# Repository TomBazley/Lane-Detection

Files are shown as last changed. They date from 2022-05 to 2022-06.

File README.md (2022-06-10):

# Lane Detection

A final year BEng electronics project that aims to detect lanes on a road from a live video feed. Using an FPGA, the lanes are detected by applying the sobel operator combined with searching for pixels brighter than a variable threshold.

## Demonstration

https://user-images.githubusercontent.com/62083547/172941356-2ffd6f28-229f-4e7b-8cfc-a31fc2a52e07.mp4

This demonstration shows a recording of the screen which displays the processed video. The red markers are produced by the FPGA to indicate the position of the lane.

## Schematic

[Schematic](https://github.com/TomBazley/Lane-Detection/blob/master/PCB/PCB.kicad_sch)

A circuit board was designed which includes an iCE40 FPGA, a VGA port for video input, a VGA-to-digital conversion chip, a STM32 microcontroller to configure the FPGA and VGA converter, and a display to view the processed images. The circuit board also features a power supply, overvoltage protection, and reverse polarity protection.

# PCB

[PCB1](https://github.com/TomBazley/Lane-Detection/blob/master/PCB/)
[PCB2](https://github.com/TomBazley/Lane-Detection/blob/master/PCB/)

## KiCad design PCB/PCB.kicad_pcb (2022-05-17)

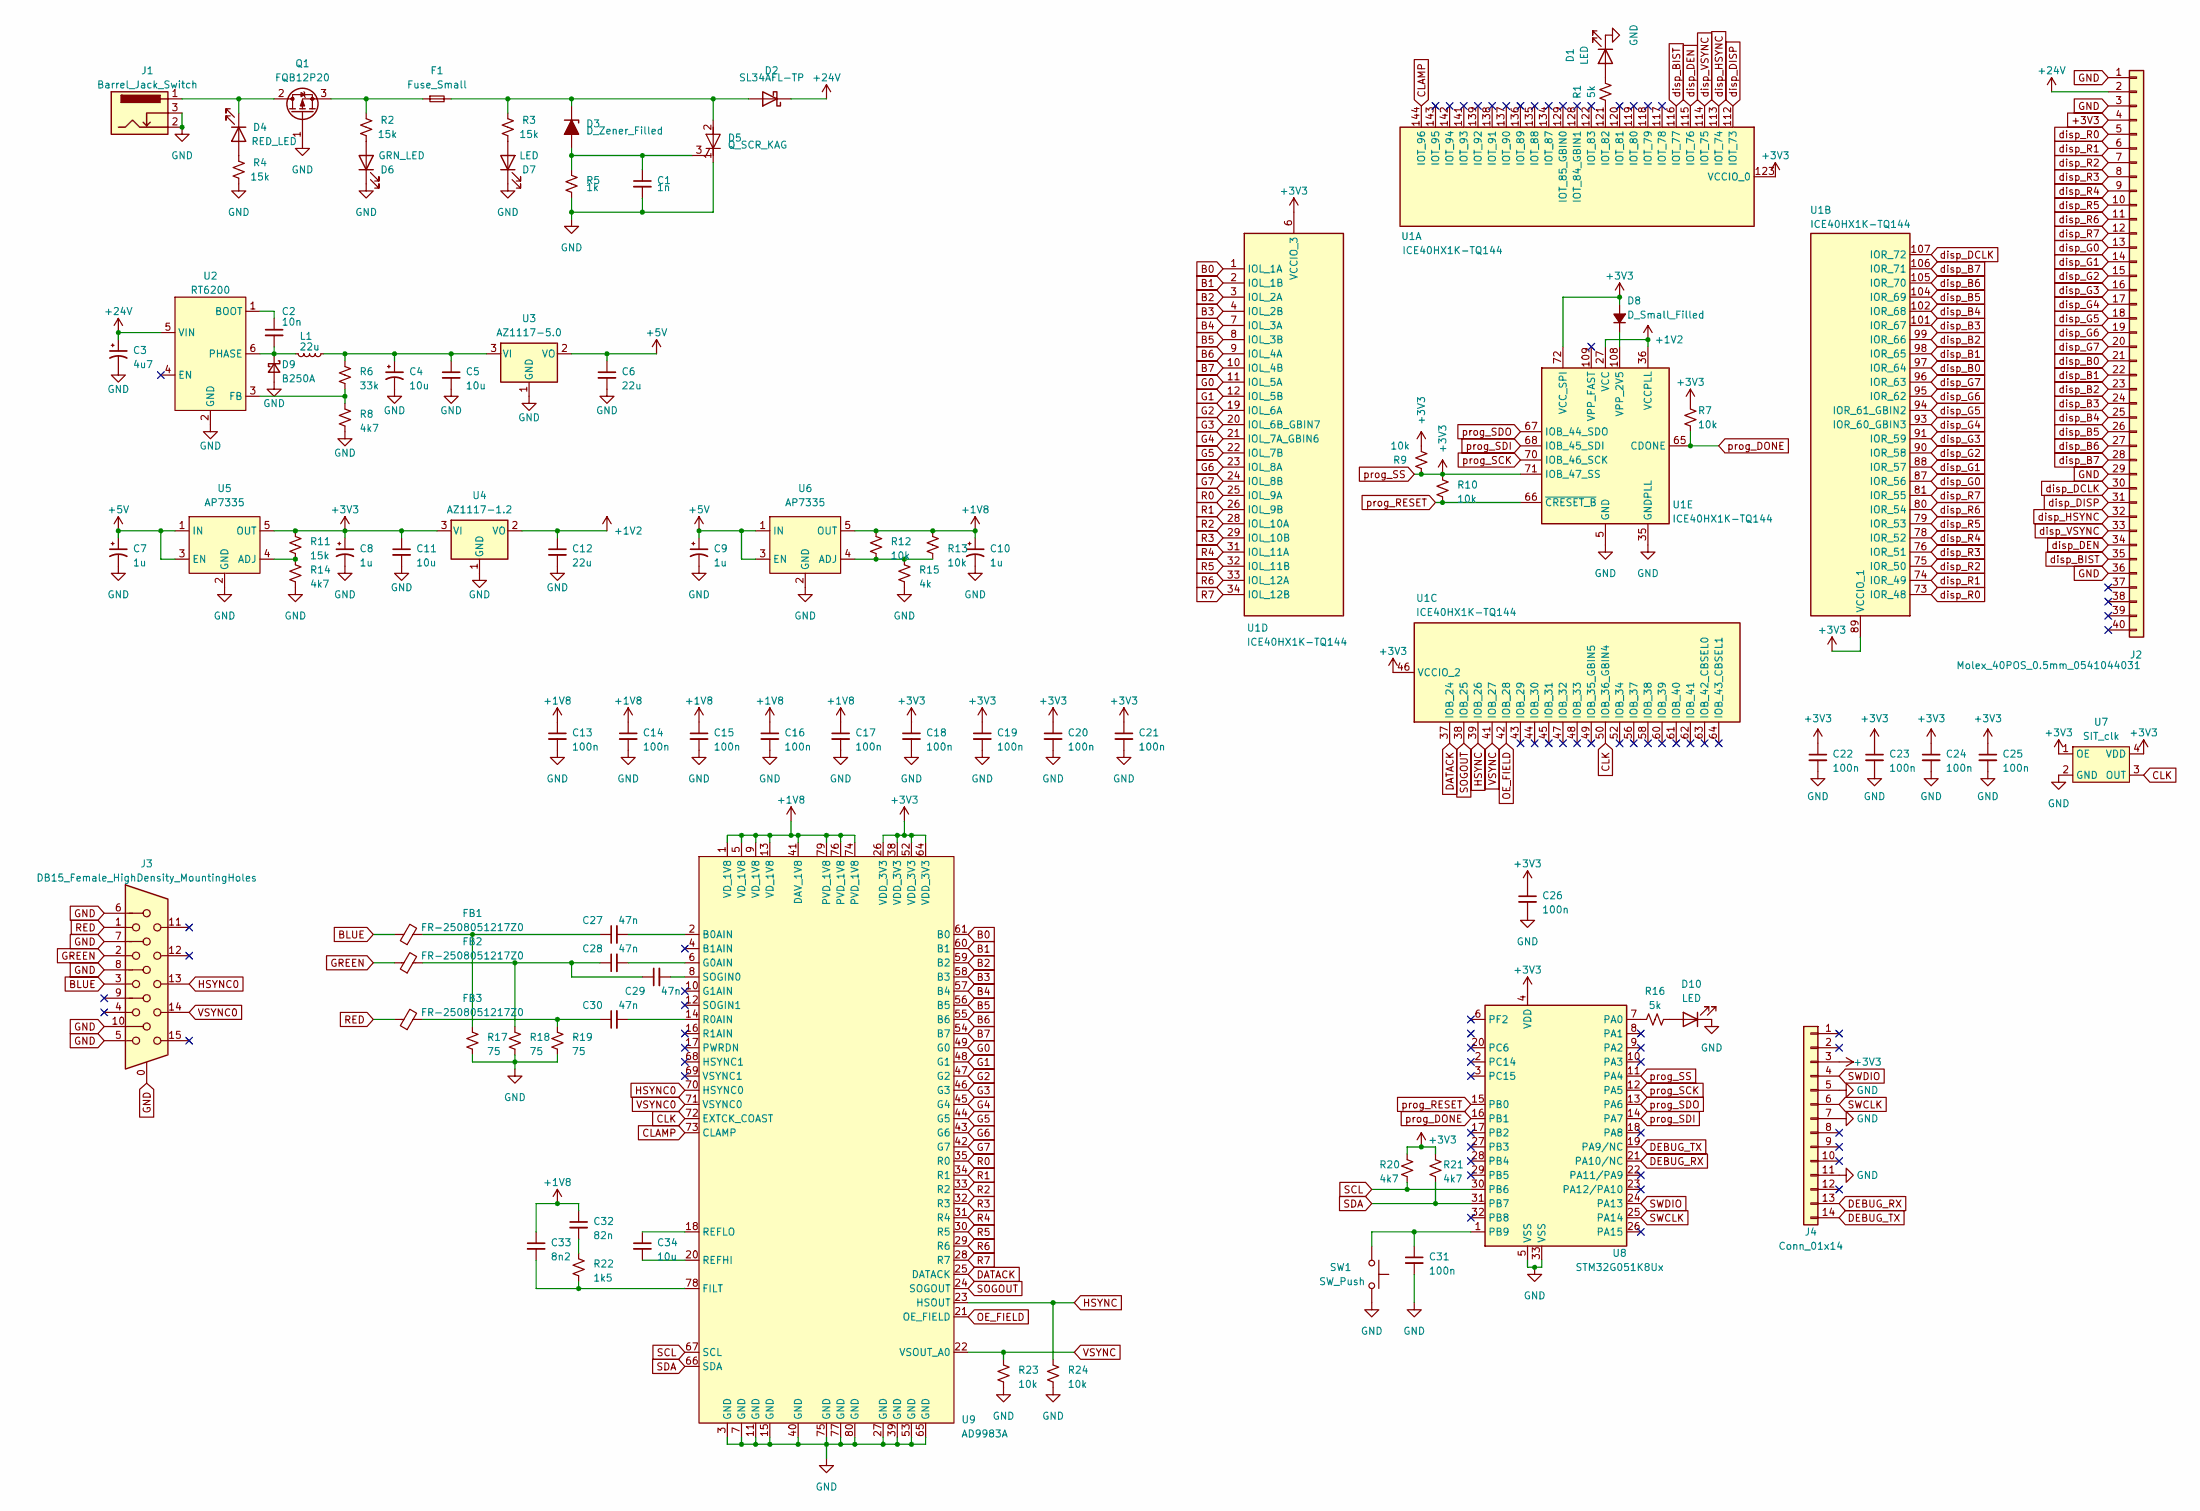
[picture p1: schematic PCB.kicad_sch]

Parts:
C1: 1n; C_0805_2012Metric
C2: 10n; C_0805_2012Metric
C3: 4u7; CP_EIA-7343-31_Kemet-D
C4: 10u; CP_EIA-7343-31_Kemet-D
C5, C11, C34: 10u; C_0805_2012Metric
C6, C12: 22u; C_0805_2012Metric
C7, C8, C9, C10: 1u; CP_EIA-3528-21_Kemet-B
C13, C14, C15, C16, C17, C18, C19, C20, C21, C22, C23, C24, C25, C26, C31: 100n; C_0805_2012Metric
C27, C28, C29, C30: 47n; C_0805_2012Metric
C32: 82n; C_0805_2012Metric
C33: 8n2; C_0805_2012Metric
D1, D7, D10: LED; LED_0603_1608Metric
D2: SL34AFL-TP; D_SMA
D3: D_Zener_Filled; D_SOD-123
D4: RED_LED; LED_0603_1608Metric
D5: Q_SCR_KAG; TO-252-2
D6: GRN_LED; LED_0603_1608Metric
D8: D_Small_Filled; D_SOD-123
D9: B250A; D_SMA
F1: Fuse_Small; Fuse_1210_3225Metric
FB1, FB2, FB3: FR-2508051217Z0; L_0805_2012Metric
J1: Barrel_Jack_Switch; Barrel PJ-002BH-SMT-TR
J2: Molex_40POS_0.5mm_0541044031
J3: DB15_Female_HighDensity_MountingHoles; VGA 10090926-P154XLF
J4: Conn_01x14; SAMTECH-FTSH-107-01-F-DV-K
L1: 22u; IHLP2525CZER220M11
Q1: FQB12P20; TO-263-2
R1, R16: 5k; R_0805_2012Metric
R2, R3, R4, R11: 15k; R_0805_2012Metric
R5: 1k; R_0805_2012Metric
R6: 33k; R_0805_2012Metric
R7, R9, R10, R12, R13, R23, R24: 10k; R_0805_2012Metric
R8, R14, R20, R21: 4k7; R_0805_2012Metric
R15: 4k; R_0805_2012Metric
R17, R18, R19: 75; R_0805_2012Metric
R22: 1k5; R_0805_2012Metric
SW1: SW_Push; SW_SPST_PTS645
U1: ICE40HX1K-TQ144; TQFP-144_20x20mm_P0.5mm
U2: RT6200; SOT-23-6
U3: AZ1117-5.0; SOT-223
U4: AZ1117-1.2; SOT-223
U5, U6: AP7335; SOT-23-5
U7: SIT_clk; SIT8008xx-1x
U8: STM32G051K8Ux; QFN-32-1EP_5x5mm_P0.5mm_EP3.45x3.45mm
U9: AD9983A; LQFP-80_14x14mm_P0.65mm

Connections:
+1V2: C12.1, U1.27 (VCC), U1.36 (VCCPLL), U1.51 (VCC), U1.92 (VCC), U1.111 (VCC), U4.2 (VO)
+1V8: C10.1, C13.1, C14.1, C15.1, C16.1, C17.1, C32.1, C33.1, R12.1, R13.1, U6.5 (OUT), U9.1 (VD_1V8), U9.5 (VD_1V8), U9.9 (VD_1V8), U9.13 (VD_1V8), U9.41 (DAV_1V8), U9.74 (PVD_1V8), U9.76 (PVD_1V8), U9.79 (PVD_1V8)
+3V3: C8.1, C11.1, C18.1, C19.1, C20.1, C21.1, C22.1, C23.1, C24.1, C25.1, C26.1, D8.2 (A), J2.4, J4.3, R7.1, R9.1, R9.2, R10.1, R11.1, R20.1, R21.1, U1.6 (VCCIO_3), U1.30 (VCCIO_3), U1.46 (VCCIO_2), U1.57 (VCCIO_2), U1.71 (IOB_47_SS), U1.72 (VCC_SPI), U1.89 (VCCIO_1), U1.100 (VCCIO_1), U1.123 (VCCIO_0), U1.133 (VCCIO_0), U4.3 (VI), U5.5 (OUT), U7.1 (OE), U7.4 (VDD), U8.4 (VDD), U8.11 (PA4), U9.26 (VDD_3V3), U9.38 (VDD_3V3), U9.52 (VDD_3V3), U9.64 (VDD_3V3)
+5V: C6.1, C7.1, C9.1, U3.2 (VO), U5.1 (IN), U5.3 (EN), U6.1 (IN), U6.3 (EN)
+24V: C3.1, D2.1 (K), J2.2, U2.5 (VIN)
B0: U1.1 (IOL_1A), U9.61 (B0)
B1: U1.2 (IOL_1B), U9.60 (B1)
B2: U1.3 (IOL_2A), U9.59 (B2)
B3: U1.4 (IOL_2B), U9.58 (B3)
B4: U1.7 (IOL_3A), U9.57 (B4)
B5: U1.8 (IOL_3B), U9.56 (B5)
B6: U1.9 (IOL_4A), U9.55 (B6)
B7: U1.10 (IOL_4B), U9.54 (B7)
BLUE: FB1.1, J3.3
CLAMP: U1.144 (IOT_96), U9.73 (CLAMP)
CLK: U1.50 (IOB_36_GBIN4), U7.3 (OUT), U9.72 (EXTCK_COAST)
DATACK: U1.37 (IOB_24), U9.25 (DATACK)
DEBUG_RX: J4.13, U8.21 (PA10/NC)
DEBUG_TX: J4.14, U8.19 (PA9/NC)
G0: U1.11 (IOL_5A), U9.49 (G0)
G1: U1.12 (IOL_5B), U9.48 (G1)
G2: U1.19 (IOL_6A), U9.47 (G2)
G3: U1.20 (IOL_6B_GBIN7), U9.46 (G3)
G4: U1.21 (IOL_7A_GBIN6), U9.45 (G4)
G5: U1.22 (IOL_7B), U9.44 (G5)
G6: U1.23 (IOL_8A), U9.43 (G6)
G7: U1.24 (IOL_8B), U9.42 (G7)
GND: C1.2, C3.2, C4.2, C5.2, C6.2, C7.2, C8.2, C9.2, C10.2, C11.2, C12.2, C13.2, C14.2, C15.2, C16.2, C17.2, C18.2, C19.2, C20.2, C21.2, C22.2, C23.2, C24.2, C25.2, C26.2, C31.2, D1.1 (K), D5.1 (K), D6.1 (K), D7.1 (K), D9.2 (A), D10.1 (K), J1.2, J1.3, J2.1, J2.3, J2.29, J2.36, J3.0, J3.5, J3.6, J3.7, J3.8, J3.10, J4.5, J4.7, J4.11, Q1.1 (G), R4.2, R5.2, R8.2, R14.2, R15.2, R17.2, R18.2, R19.2, R23.2, R24.2, SW1.2, U1.5 (GND), U1.13 (GND), U1.14 (GND), U1.35 (GNDPLL), U1.59 (GND), U1.69 (GND), U1.86 (GND), U1.103 (GND), U1.132 (GND), U1.140 (GND), U2.2 (GND), U3.1 (GND), U4.1 (GND), U5.2 (GND), U6.2 (GND), U7.2 (GND), U8.5 (VSS), U8.33 (VSS), U9.3 (GND), U9.7 (GND), U9.11 (GND), U9.15 (GND), U9.27 (GND), U9.39 (GND), U9.40 (GND), U9.53 (GND), U9.65 (GND), U9.75 (GND), U9.77 (GND), U9.80 (GND)
GREEN: FB2.1, J3.2
HSYNC: R24.1, U1.39 (IOB_26), U9.23 (HSOUT)
HSYNC0: J3.13, U9.70 (HSYNC0)
unnamed: C27.1, FB1.2, R17.1
unnamed: C28.1, C29.1, FB2.2, R18.1
unnamed: C30.1, FB3.2, R19.1
unnamed: C32.2, R22.1
unnamed: D1.2 (A), R1.2
unnamed: D2.2 (A), D3.1 (K), D5.2 (A), F1.2, R3.1
unnamed: C1.1, D3.2 (A), D5.3 (G), R5.1
unnamed: D4.2 (A), R4.1
unnamed: D4.1 (K), J1.1, Q1.2 (D)
unnamed: D6.2 (A), R2.2
unnamed: D7.2 (A), R3.2
unnamed: D8.1 (K), U1.108 (VPP_2V5)
unnamed: C2.2, D9.1 (K), L1.1, U2.6 (PHASE)
unnamed: D10.2 (A), R16.2
unnamed: F1.1, Q1.3 (S), R2.1
unnamed: R1.1, U1.121 (IOT_82)
unnamed: C2.1, U2.1 (BOOT)
unnamed: R6.2, R8.1, U2.3 (FB)
unnamed: C4.1, C5.1, L1.2, R6.1, U3.3 (VI)
unnamed: R11.2, R14.1, U5.4 (ADJ)
unnamed: R12.2, R13.2, R15.1, U6.4 (ADJ)
unnamed: R16.1, U8.7 (PA0)
unnamed: C31.1, SW1.1, U8.1 (PB9)
unnamed: C27.2, U9.2 (B0AIN)
unnamed: C33.2, R22.2, U9.78 (FILT)
unnamed: C28.2, U9.6 (G0AIN)
unnamed: C30.2, U9.14 (R0AIN)
unnamed: C34.2, U9.20 (REFHI)
unnamed: C34.1, U9.18 (REFLO)
unnamed: C29.2, U9.8 (SOGIN0)
OE_FIELD: U1.42 (IOB_28), U9.21 (OE_FIELD)
R0: U1.25 (IOL_9A), U9.35 (R0)
R1: U1.26 (IOL_9B), U9.34 (R1)
R2: U1.28 (IOL_10A), U9.33 (R2)
R3: U1.29 (IOL_10B), U9.32 (R3)
R4: U1.31 (IOL_11A), U9.31 (R4)
R5: U1.32 (IOL_11B), U9.30 (R5)
R6: U1.33 (IOL_12A), U9.29 (R6)
R7: U1.34 (IOL_12B), U9.28 (R7)
RED: FB3.1, J3.1
SCL: R20.2, U8.30 (PB6), U9.67 (SCL)
SDA: R21.2, U8.31 (PB7), U9.66 (SDA)
SOGOUT: U1.38 (IOB_25), U9.24 (SOGOUT)
SWCLK: J4.6, U8.25 (PA14)
SWDIO: J4.4, U8.24 (PA13)
VSYNC: R23.1, U1.41 (IOB_27), U9.22 (VSOUT_A0)
VSYNC0: J3.14, U9.71 (VSYNC0)
disp_B0: J2.21, U1.97 (IOR_64)
disp_B1: J2.22, U1.98 (IOR_65)
disp_B2: J2.23, U1.99 (IOR_66)
disp_B3: J2.24, U1.101 (IOR_67)
disp_B4: J2.25, U1.102 (IOR_68)
disp_B5: J2.26, U1.104 (IOR_69)
disp_B6: J2.27, U1.105 (IOR_70)
disp_B7: J2.28, U1.106 (IOR_71)
disp_BIST: J2.35, U1.116 (IOT_77)
disp_DCLK: J2.30, U1.107 (IOR_72)
disp_DEN: J2.34, U1.115 (IOT_76)
disp_DISP: J2.31, U1.112 (IOT_73)
disp_G0: J2.13, U1.87 (IOR_56)
disp_G1: J2.14, U1.88 (IOR_57)
disp_G2: J2.15, U1.90 (IOR_58)
disp_G3: J2.16, U1.91 (IOR_59)
disp_G4: J2.17, U1.93 (IOR_60_GBIN3)
disp_G5: J2.18, U1.94 (IOR_61_GBIN2)
disp_G6: J2.19, U1.95 (IOR_62)
disp_G7: J2.20, U1.96 (IOR_63)
disp_HSYNC: J2.32, U1.113 (IOT_74)
disp_R0: J2.5, U1.73 (IOR_48)
disp_R1: J2.6, U1.74 (IOR_49)
disp_R2: J2.7, U1.75 (IOR_50)
disp_R3: J2.8, U1.76 (IOR_51)
disp_R4: J2.9, U1.78 (IOR_52)
disp_R5: J2.10, U1.79 (IOR_53)
disp_R6: J2.11, U1.80 (IOR_54)
disp_R7: J2.12, U1.81 (IOR_55)
disp_VSYNC: J2.33, U1.114 (IOT_75)
prog_DONE: R7.2, U1.65 (CDONE), U8.16 (PB1)
prog_RESET: R10.2, U1.66 (~CRESET_B), U8.15 (PB0)
prog_SCK: U1.70 (IOB_46_SCK), U8.12 (PA5)
prog_SDI: U1.68 (IOB_45_SDI), U8.14 (PA7)
prog_SDO: U1.67 (IOB_44_SDO), U8.13 (PA6)

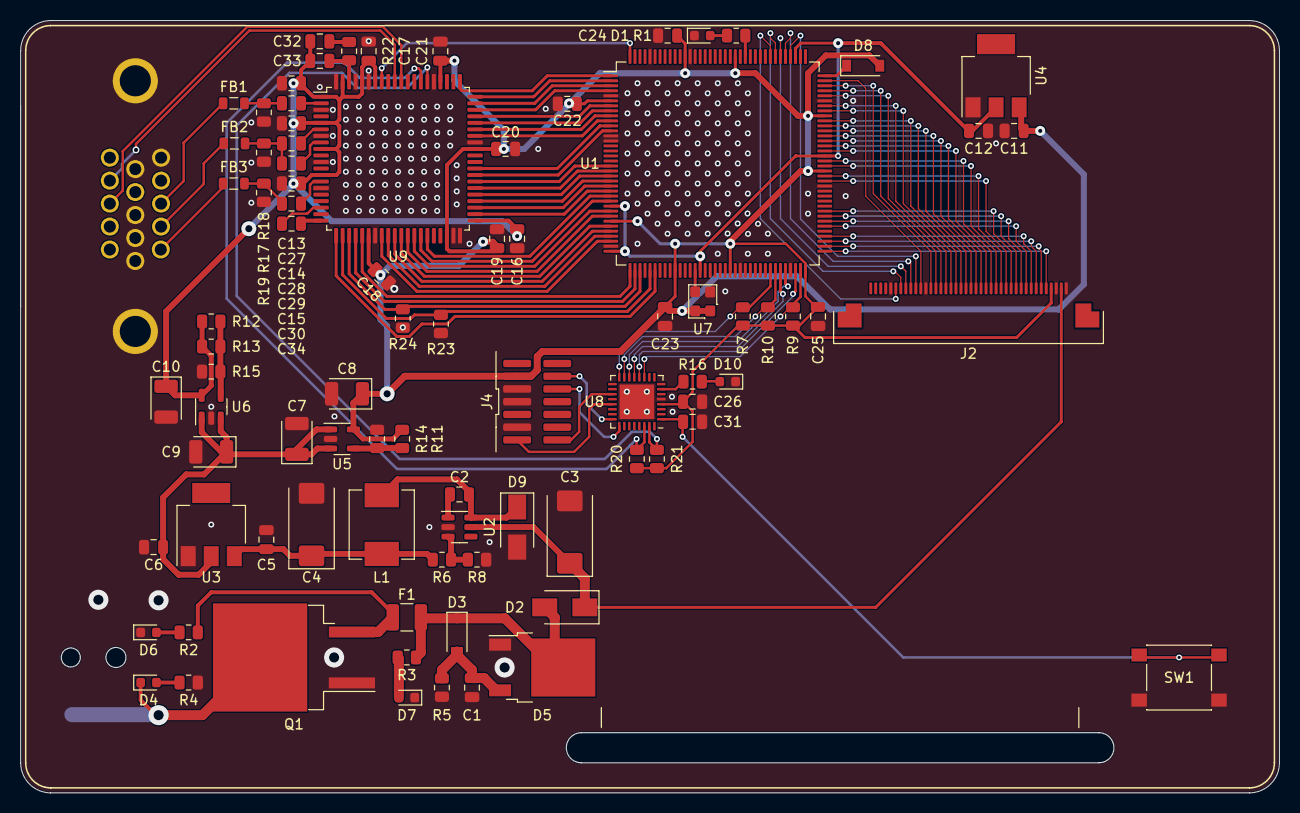
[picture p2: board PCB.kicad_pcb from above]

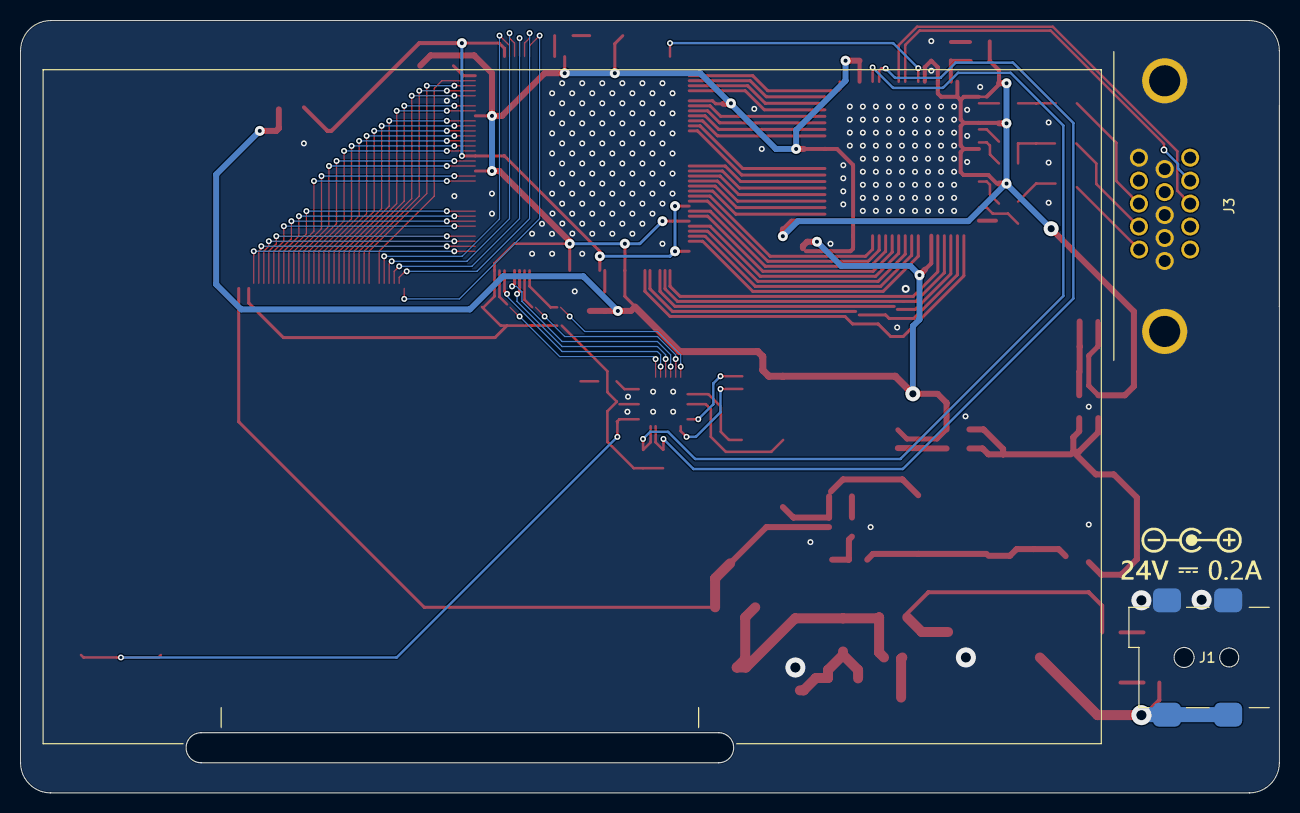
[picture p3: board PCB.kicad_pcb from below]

Board: 2 copper layers, 125.5 x 77.0 mm, 88 parts (2 on the bottom side), 113 nets.

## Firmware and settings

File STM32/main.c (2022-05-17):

// Copyright 2022 Tom Bazley tombazley@outlook.com
// SPDX-License-Identifier: Apache-2.0 WITH SHL-2.1
// 
// Licensed under the Solderpad Hardware License v 2.1 (the “License”); you may
// not use this file except in compliance with the License, or, at your option,
// the Apache License version 2.0. You may obtain a copy of the License at
//
// https://solderpad.org/licenses/SHL-2.1/
//
// Unless required by applicable law or agreed to in writing, any work
// distributed under the License is distributed on an “AS IS” BASIS, WITHOUT
// WARRANTIES OR CONDITIONS OF ANY KIND, either express or implied. See the
// License for the specific language governing permissions and limitations under
// the License.

#include <stm32g0xx.h>
#include "ice40.h"
#include "ad9983a.h"

#define PIN_SS 4

static uint8_t mode[11] = {
  0x11, 0x12, 0x13, 0x17, //luma
  0x11, 0x12, 0x14, 0x15, 0x27, //edge
  0x16, 0x37 //combined
};

static uint8_t n = 0;

static void send_mode(uint8_t byte) {
  GPIOA->ODR &= ~(1 << PIN_SS);
  send_data(byte);
  while (SPI1->SR & SPI_SR_BSY) { __NOP(); }
  GPIOA->ODR |= (1 << PIN_SS);
  for (int n = 0; n < 1000000; n++) __NOP();
}

int main () {
  RCC->IOPENR |= RCC_IOPENR_GPIOAEN |
                 RCC_IOPENR_GPIOBEN;

  GPIOA->MODER &= ~(3 << 0);
  GPIOA->MODER |= (1 << 0);

  GPIOB->MODER &= ~(3 << (2 * 9));
  GPIOB->PUPDR |= (1 << (2 * 9));

  ad9983a_configure();

  ice40_configure();
  
  send_mode(mode[n]);
  
  while(1) {
    if (!(GPIOB->IDR & (1 << 9))) {
      n = (n + 1 == sizeof(mode) ? 0: n + 1);
      send_mode(mode[n]);
    }
  }
}

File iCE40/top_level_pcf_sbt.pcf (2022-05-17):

# ##############################################################################

# iCEcube PCF

# Version:            2020.12.27943

# File Generated:     Apr 4 2022 16:43:52

# Family & Device:    iCE40HX1K

# Package:            TQ144

# ##############################################################################

###IOSet List 2
set_io clk 37

set_io mosi 68
set_io sck 70
set_io cs_n 71

set_io b_in[0] 1
set_io b_in[1] 2
set_io b_in[2] 3
set_io b_in[3] 4
set_io b_in[4] 7
set_io b_in[5] 8
set_io b_in[6] 9
set_io b_in[7] 10
set_io g_in[0] 11
set_io g_in[1] 12
set_io g_in[2] 19
set_io g_in[3] 20
set_io g_in[4] 21
set_io g_in[5] 22
set_io g_in[6] 23
set_io g_in[7] 24
set_io r_in[0] 25
set_io r_in[1] 26
set_io r_in[2] 28
set_io r_in[3] 29
set_io r_in[4] 31
set_io r_in[5] 32
set_io r_in[6] 33
set_io r_in[7] 34
set_io sogout 38
set_io hsync 39
set_io vsync 41
set_io oe_field 42
set_io clamp 144

set_io r_out[0] 73
set_io r_out[1] 74
set_io r_out[2] 75
set_io r_out[3] 76
set_io r_out[4] 78
set_io r_out[5] 79
set_io r_out[6] 80
set_io r_out[7] 81
set_io g_out[0] 87
set_io g_out[1] 88
set_io g_out[2] 90
set_io g_out[3] 91
set_io g_out[4] 93
set_io g_out[5] 94
set_io g_out[6] 95
set_io g_out[7] 96
set_io b_out[0] 97
set_io b_out[1] 98
set_io b_out[2] 99
set_io b_out[3] 101
set_io b_out[4] 102
set_io b_out[5] 104
set_io b_out[6] 105
set_io b_out[7] 106
set_io disp_clk 107
set_io disp_disp 112
set_io disp_hsync 113
set_io disp_vsync 114
set_io disp_den 115
set_io disp_bist 116

set_io led 121
